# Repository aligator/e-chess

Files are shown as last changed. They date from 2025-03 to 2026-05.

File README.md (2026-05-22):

# E-Chess

# MOVED to https://codeberg.org/aligator/e-chess

This project is a physical chess board that is connected to an online chess
server (currently lichess).\
It allows to play chess on a physical board with a computer/remote opponent.

It is currently **WIP** so no full documentation and information is available
yet.\
However there exists already a working prototype including:

- ESP32-S3 Rust firmware
- Android app
- connection to lichess (to lichess via the android app using BLE - web on the
  esp32s3 was too unstable and slow)
- LEDs in the board to show the current game state
- 3d printable OpenSCAD file
- KiCAD electronics schematic

## Future plans

- more gameplay features
- ble over secure connection (currently unencrypted!)
- more easy hardware design (maybe PCB for the whole board?)
- Documentation
- ...

## AI Disclaimer

Yes, I use some AI for this project (especially for the Android app, since I am
not that interested in writing apps...), but the code-architecture, most
firmware code, scad, electronics and the overall design is my own.

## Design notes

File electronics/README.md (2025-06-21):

# E-Chess Electronics

This contains the schematic for the chess board.  
It is designed for an ESP32-S3 development board.  

Currently it is wired completely manually. Therefore it does not contain a PCB yet.

## LEDs

The schematic contains one single LED as placeholder for all 64 WS2812 LEDs.  
They are routed in a snake pattern from the top right to the bottom right.
```
┌💡─💡─💡─💡─💡─💡─💡─💡 <- START
└💡─💡─💡─💡─💡─💡─💡─💡┐
┌💡─💡─💡─💡─💡─💡─💡─💡┘
└💡─💡─💡─💡─💡─💡─💡─💡┐
┌💡─💡─💡─💡─💡─💡─💡─💡┘
└💡─💡─💡─💡─💡─💡─💡─💡┐
┌💡─💡─💡─💡─💡─💡─💡─💡┘
└💡─💡─💡─💡─💡─💡─💡─💡 -> END
``` 

## Reed sensors

For the Reed sensors a matrix with simple reed contacts is used.  
It resembles the matrix described [here](https://www-user.tu-chemnitz.de/~heha/Mikrocontroller/Tastenmatrix.htm).

The IO expander MCP23017 is used to connect the columns and rows.  
As it has exactly 16 pins, it matches exactly the required 8x8 matrix.

The MCP23017 has built in pull-up resistors, so no external resistors are needed.

GPB (pin 0 - 7) is used as output for the columns.  
GPA (pin 21 - 28) is used as input for the rows.  

The matrix resembles the actual chess board starting with A1 at the bottom left.  
So A1 == GPB0|GPA0, A2 == GPB1|GPA0, ... H8 == GPB7|GPA7.

To read the status, the firmware will set all rows but one to high and then read the columns.  
Then it will do the same for the next row.  

## Power supply

The ESP32-S3 is powered by the USB-C connector.  

* Since the esp works with 3.3V, the IO expander is also running on 3.3V.  
* Since the LEDs are WS2812B, they need 5V, coming from the ESP dev board. 
 **You may need to connect the IN-OUT jumper on the ESP dev board to receive 5V on the 5V-pin.**

For now my plan is to avoid driving the LEDS with full power.  
I try to handle everything with 500 mA. However this may need to be changed later.

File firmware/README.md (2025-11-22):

# E-Chess Firmware

This is the firmware for the E-Chess project, written in Rust using the ESP-IDF framework.

**This project works best with the ESP32-S3 (with 16mb flash) dev board.**
**The ESP32 is currently still in the firmware, but not recommended.**

For OTA to work, see the requirements in the [OTA Support](#ota-support) section.

## Prerequisites

- Rust (latest stable)
- ESP-IDF ([see the docs](https://docs.espressif.com/projects/rust/book/getting-started/toolchain.html))

## Quick Start

```bash
# Build, flash and watch logs (effectively cargo run)
./build.sh run esp32s3 --release

# Just watch logs via usb (if it is already running on the esp)
./build.sh watch

# Build and deploy via OTA (and optionally watch - only if connected via usb)
./build.sh ota 192.168.4.1 esp32s3 --release --watch
```

For more options and commands, run:
```bash
./build.sh --help
```

## OTA Support

For OTA updates, you need a flash size of at least 8MB *(16MB recommended!)* since the firmware is already > 2MB.
The flash must be partitioned with two slots.

**16MB is recommended!**  
8MB should also work for now, but the firmware may get bigger some day.  
Due to using rust std, this firmware is definitely not the smallest.

Either:
1. Copy the appropriate file (compatible to running with `cargo run`):
```bash
# For 8MB flash
cp espflash_ota_8mb.toml espflash.toml

# For 16MB flash
cp espflash_ota_16mb.toml espflash.toml
```

2. Or use the --partition-table flag:
```bash
# For 8MB flash
./build.sh run esp32s3 --flash-size 8mb

# For 16MB flash
./build.sh run esp32s3 --flash-size 16mb
```

## Development

1. Make sure you have all prerequisites installed
2. Connect your ESP32 via USB
3. Use `./build.sh run esp32s3 --watch` to build, flash and watch logs
4. Use `./build.sh watch` to just watch logs without building/flashing

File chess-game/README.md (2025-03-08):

# Rust Chess game

This project contains the base handling of a chess game.  
It can be run directly for testing by providing a cli prompt simulating the physical chess board.

As input it works with a single bit board that tells which square is occupied.
At any time this `physical` representation should only differ from the last observed state by one single part.
Otherwise it is not possible to distinguish what should happen in this step.

If the board gets in an invalid state it will stop doing anything.

If it is only one pice (either removed or added), it will be validated:
* based on the current game state (e.g. which player)
* if the last action is not complete yet, check if the new state completes it 
(e.g. moving a piece - 1. take it 2. place it on the new spot)
* is the move a valid chess move

To simulate the board for development there are only two comments to simulate the physical behavior:
* take b5
* put b5

after each action the cli prints out the new board state as ASCII.
The background color encodes the real chess color with black and grey for visualization.

But if a piece is wrong it is color coded this way:
* Blue - physical piece missing
* Red - physical piece should be here but it isn't

## Examples

### Simulator

The project includes a simulator example which can be run with:

```
cargo run --example simulator
```

This example requires the `reqwest` feature, which is enabled by default in the project configuration, so no additional flags are needed.

## Features

The project has the following features:

- `colored-debug`: Enables colored output in debug mode (enabled by default)
- `reqwest`: Enables a default implementation using reqwest and tokio

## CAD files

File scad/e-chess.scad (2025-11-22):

renderTopBoard = true;

// Enable multicolor using an extra layer.
renderLayeredMultiColorBoard = true;

// Switches the fields that get the extra layer. (e.g. to change the color on a specific layer manually.) Cannot be used together with renderMultiColorBoardColorX.
topBoardLayeredMultiColorEven = false;

// Enables multi-color Color1 (e.g. support for mulit-color printers.) Cannot be used together with topBoardLayeredMultiColorEven.
renderMultiColorBoardColor1 = false;
// Enables multi-color Color2 (e.g. support for mulit-color printers.) Cannot be used together with topBoardLayeredMultiColorEven.
renderMultiColorBoardColor2 = false;

renderTopGrid = true;
renderGrid = true;
renderBottom = true;
renderElectronicCase = true;
renderElectronicCaseCover = true;
renderReedPins = true;
// Just for debugging
renderMetalPlate = false;
flipElectronicCaseCover = false;
renderPCB = false;
pcbWidth = 179.4;
pcbHeight = 40.02;
pcbTopSpacing = 15;
pcbHoles = [
  [4.3, 4.3],
  [4.3, pcbHeight - 4.3],
  [148.7, pcbHeight / 2 + 0.45],
];
pcbSpacerHeight = 5;
pcbScrewDiameter = 4;
pcbSpacerDiameter = 8;

// Experimental - not really nice...
extraReedPinCutout = false;

// More easy to add the wires, but may lead to light bleeding into neightbour fields.
electronicCutoutInBorder = true;

renderPrintable = true;

cutParts = false;

// Also must match the led-strip led distance
fieldSize = 33;

// Board field count. For a normal chess -> 8.
size = 8;

top = 2.0;

topBoardHeight = 0.4;
topBoardMultiColorHeight = 0.2;

// Border on each field. Note that two borders side by side lead to an effective *2 border.
fieldBorder = 1;

wireRadius = 1.5;

boxHeight = 30;

ledWidth = 11;
ledHeight = 4;
bottomHeight = 5;

// Additional bottomWallSize to the size of the grid.
bottomWallSize = 5;

electronicCaseWidth = 50;
electronicBreakThrough = 9;

electronicCaseCover = 1;
electronicCaseCoverBorder = 1;
// Maybe use screws in the next version instead of the border?
// However my current printed prototype doesn't have this yet.
// electronicCaseCoverScrewsDiameter = 4;
// electronicCaseCoverScrewsOuterDiameter = 8;

// I use this display: Waveshare 1.54 Inch E-Paper Display Panel Module Kit 200 * 200 https://www.amazon.de/dp/B0728BJTZC?ref=ppx_yo2ov_dt_b_fed_asin_title
displayWidth = 32;
displayHeight = 38;
displayScrewDiameter = 3.3;
displayScrewOffsetX = -1.75;
displayScrewOffsetY = 2.8;
displaySpacerHeight = 1.5;
displayBottomSpacing = 3;
displayBottomOverlap = 6;

displaySpacerDiameter = displayScrewDiameter + (max(displayScrewOffsetX, displayScrewOffsetY) - displayScrewDiameter / 2) * 2;

// Offset of the buttons from the display edge (below the display).
displayButtonsOffsetY = 8;
// Spacing between the buttons.
displayButtonsSpacing = 15;
displayButtonDiameter = 7;

usbCutoutDia = 10;
usbCutoutDiaCover = 15;

reedPinBorder = 3;
metalPlateThickness = 0.3;
metalPlateRadius = 7.5;
reedThickness = 3.3;
reedWireThickness = 2;
reedOffset = 5;

tolerance = 0.4;

ledWallCutout = 2.0;

coverWidth = electronicCaseWidth - bottomWallSize - 2 * tolerance;

echo("available electronic width: ", coverWidth - 2 * electronicCaseCoverBorder);

reedPinHeight = boxHeight - topBoardHeight - top - metalPlateThickness;

// Just a constant to make cutouts larger for better preview rendering.
c0 = 0.01 + 0;

$fa = 3;
$fs = 0.2;

gridInner = size * fieldSize;
gridOuter = gridInner + 2 * fieldBorder;
cutPartsSize = cutParts ? 10 : 0;

fullOuterBoard = gridOuter + 2 * bottomWallSize + 2 * tolerance;

reedPinWidth = ledWidth + reedPinBorder * 2;

module eachGrid(count = size) {
  for (i = [0:1:count - 1]) {
    for (j = [0:1:count - 1]) {
      translate([i * fieldSize, j * fieldSize, 0]) children();
    }
  }
}

module cut4(partSize, gap) {
  if (gap == 0) {
    // Fast path to avoid unneeded rendering
    children();
  } else {
    for (i = [0:1:1]) {
      for (j = [0:1:1]) {
        translate(
          [i * partSize[0] / 2 + i * gap, j * partSize[1] / 2 + j * gap, 0]
        )
          intersection() {
            translate([-i * partSize[0] / 2, -j * partSize[1] / 2]) children();
            cube([partSize[0] / 2, partSize[1] / 2, partSize[2]]);
          }
      }
    }
  }
}

module cut2(partSize, gap, translation = [0, 0, 0]) {
  if (gap == 0) {
    // Fast path to avoid unneeded rendering
    children();
  } else {
    i = 0;
    for (j = [0:1:1]) {
      translate([0, j * partSize[1] / 2 + j * gap, 0]) intersection() {
          translate([0, -j * partSize[1] / 2]) children();
          translate(translation)
            cube([partSize[0], partSize[1] / 2, partSize[2]]);
        }
    }
  }
}

module Field(height) {
  difference() {
    cube([fieldSize, fieldSize, height]);
    translate([fieldBorder, fieldBorder, -c0]) cube(
        [
          fieldSize - fieldBorder * 2,
          fieldSize - fieldBorder * 2,
          height + c0 * 2,
        ]
      );
  }
  ;
}

module LayeredMultiColorBoard() {
  for (i = [0:1:size - 1]) {
    for (j = [0:1:size - 1]) {
      if ( (i + j) % 2 == (topBoardLayeredMultiColorEven ? 0 : 1)) {

        translate(
          [
            i * fieldSize,
            j * fieldSize,
            topBoardHeight,
          ]
        ) {
          cube(
            [
              fieldSize - tolerance * 2 - fieldBorder * 2,
              fieldSize - tolerance * 2 - fieldBorder * 2,
              topBoardMultiColorHeight,
            ]
          );
        }
        ;
      }
    }
  }
}

module MultiColorBoard1(count) {
  difference() {
    cube(
      [
        fieldSize * count,
        fieldSize * count,
        topBoardHeight,
      ]
    );

    for (i = [0:1:count - 1]) {
      for (j = [0:1:count - 1]) {
        if ( (i + j) % 2 == (renderPrintable ? 0 : 1)) {

          translate(
            [
              i * fieldSize,
              j * fieldSize,
              topBoardHeight - topBoardMultiColorHeight,
            ]
          ) {
            cube(
              [
                fieldSize,
                fieldSize,
                topBoardMultiColorHeight + c0,
              ]
            );
          }
          ;
        }
      }
    }
  }
}

module MultiColorBoard2(count) {
  for (i = [0:1:count - 1]) {
    for (j = [0:1:count - 1]) {
      if ( (i + j) % 2 == (renderPrintable ? 0 : 1)) {

        translate(
          [
            i * fieldSize,
            j * fieldSize,
            topBoardHeight - topBoardMultiColorHeight,
          ]
        ) {
          cube(
            [
              fieldSize,
              fieldSize,
              topBoardMultiColorHeight + c0,
            ]
          );
        }
        ;
      }
    }
  }
}

module BaseBoard() {
  cube(
    [
      gridInner - tolerance * 2 - fieldBorder * 2,
      gridInner - tolerance * 2 - fieldBorder * 2,
      topBoardHeight,
    ]
  );
}

module TopBoard() {
  // When rendering printable and with the multi color approach - render only one of the 4 parts.
  // Otherwise the handling in the slicer is hard.
  // You have to print it 4 times.
  multiColorSize = renderPrintable ? size / 2 : size;

  difference() {
    union() {
      if (!renderMultiColorBoardColor1 && !renderMultiColorBoardColor2) {
        translate([fieldBorder, fieldBorder, 0]) {
          BaseBoard();
          if (renderLayeredMultiColorBoard) {
            LayeredMultiColorBoard();
          }
        }
      }
      if (renderMultiColorBoardColor1) {
        MultiColorBoard1(multiColorSize);
      }
      ; if (renderMultiColorBoardColor2) {
        MultiColorBoard2(multiColorSize);
      }
      ;
    }
    ;

    // Cut away borders around the 4 slots.
    translate([0, (gridInner / 2) - tolerance * 2 - fieldBorder, -c0])
      cube([gridInner, fieldBorder * 2 + tolerance * 2, topBoardHeight + c0 * 2]);
    translate([(gridInner / 2) - tolerance * 2 - fieldBorder, 0, -c0])
      cube([fieldBorder * 2 + tolerance * 2, gridInner, topBoardHeight + c0 * 2]);

    translate([0, 0, -c0])
      difference() {
        cube(
          [
            gridInner,
            gridInner,
            topBoardHeight + topBoardMultiColorHeight + 2 * c0,
          ]
        );
        translate([fieldBorder, fieldBorder, 0]) {
          cube(
            [
              gridInner - tolerance * 2 - fieldBorder * 2,
              gridInner - tolerance * 2 - fieldBorder * 2,
              topBoardHeight + topBoardMultiColorHeight + 2 * c0,
            ]
          );
        }
        ;
      }
    ;
  }
}

module TopGrid() {
  difference() {
    union() {
      // Render border
      translate([0, 0, bottomHeight]) difference() {
          cube(
            [
              gridInner + fieldBorder * 2,
              gridInner + fieldBorder * 2,
              boxHeight,
            ]
          );
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

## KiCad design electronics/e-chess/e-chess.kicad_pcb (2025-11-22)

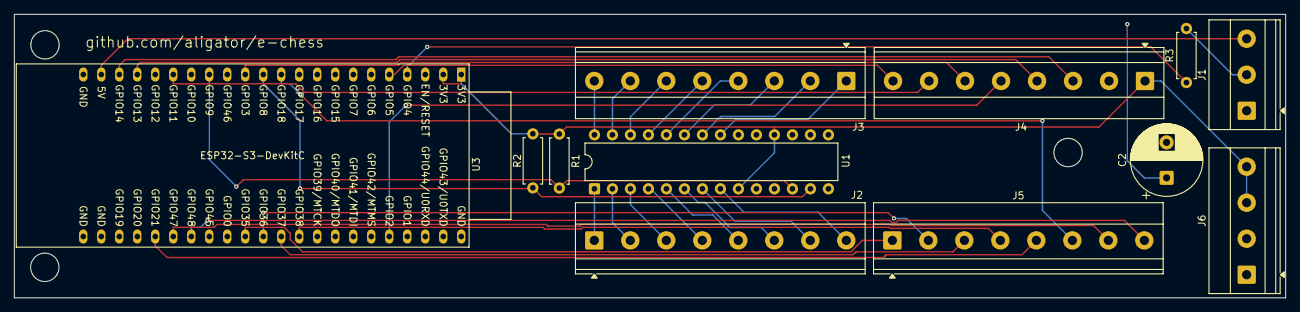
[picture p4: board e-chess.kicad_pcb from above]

Board: 2 copper layers, 179.4 x 40.0 mm, 15 parts (0 on the bottom side), 37 nets.

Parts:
C2: 470 µF; CP_Radial_D10.0mm_P5.00mm
J1: WS2812_LEDs; TerminalBlock_Phoenix_MKDS-1,5-3-5.08_1x03_P5.08mm_Horizont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
J2: Outputs; TerminalBlock_Phoenix_MKDS-1,5-8-5.08_1x08_P5.08mm_Horizont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
J3: Inputs; TerminalBlock_Phoenix_MKDS-1,5-8-5.08_1x08_P5.08mm_Horizont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
J4: e-Paper 1.54 inch; TerminalBlock_Phoenix_MKDS-1,5-8-5.08_1x08_P5.08mm_Horizont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
J5: Arbitary I/O; TerminalBlock_Phoenix_MKDS-1,5-8-5.08_1x08_P5.08mm_Horizont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
J6: Power for I/O; TerminalBlock_Phoenix_MKDS-1,5-4-5.08_1x04_P5.08mm_Horizont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
R1, R2: R4.7k; R_Axial_DIN0207_L6.3mm_D2.5mm_P7.62mm_Horizontal
R3: R470; R_Axial_DIN0207_L6.3mm_D2.5mm_P7.62mm_Horizontal
REF00, REF01, REF02: MountingHole_4mm
U1: MCP23017_SP; DIP-28_W7.62mm
U3: ESP32-S3-DevKitC

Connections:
+3.3V: J4.1 (VCC), J6.3 (3V3), J6.4 (3V3), R1.2, R2.2, U1.9 (VDD), U1.18 (~RESET), U3.1 (3V3), U3.2 (3V3)
+5V: C2.1, J1.3 (VDD), U3.21 (5V)
GND: C2.2, J1.1 (GND), J4.2 (GND), J6.1 (GND), J6.2 (GND), U1.10 (VSS), U1.15 (A0), U1.16 (A1), U1.17 (A2), U3.22 (GND), U3.23 (GND), U3.24 (GND), U3.44 (GND)
unnamed: J1.2 (DIN), R3.2
unnamed: J2.1, U1.1 (GPB0)
unnamed: J2.2, U1.2 (GPB1)
unnamed: J2.3, U1.3 (GPB2)
unnamed: J2.4, U1.4 (GPB3)
unnamed: J2.5, U1.5 (GPB4)
unnamed: J2.6, U1.6 (GPB5)
unnamed: J2.7, U1.7 (GPB6)
unnamed: J2.8, U1.8 (GPB7)
unnamed: J3.1, U1.21 (GPA0)
unnamed: J3.2, U1.22 (GPA1)
unnamed: J3.3, U1.23 (GPA2)
unnamed: J3.4, U1.24 (GPA3)
unnamed: J3.5, U1.25 (GPA4)
unnamed: J3.6, U1.26 (GPA5)
unnamed: J3.7, U1.27 (GPA6)
unnamed: J3.8, U1.28 (GPA7)
unnamed: J4.8 (BUSY), U3.5 (GPIO5/ADC1_CH4)
unnamed: J4.4 (CLK), U3.19 (GPIO13/ADC2_CH2)
unnamed: J4.5 (CS), U3.40 (GPIO2/ADC1_CH1)
unnamed: J4.6 (DC), U3.13 (GPIO3/ADC1_CH2)
unnamed: J4.3 (DIN), U3.20 (GPIO14/ADC2_CH3)
unnamed: J4.7 (RST), U3.17 (GPIO11/ADC2_CH0)
unnamed: J5.6 (GPIO18), U3.11 (GPIO18/ADC2_CH7)
unnamed: J5.5 (GPIO21), U3.27 (GPIO21)
unnamed: J5.1 (GPIO35), U3.32 (GPIO35)
unnamed: J5.2 (GPIO36), U3.33 (GPIO36)
unnamed: J5.3 (GPIO37), U3.34 (GPIO37)
unnamed: J5.4 (GPIO38), U3.35 (GPIO38)
unnamed: J5.7 (GPIO47), U3.28 (GPIO47)
unnamed: J5.8 (GPIO48), U3.29 (GPIO48)
unnamed: R1.1, U1.12 (SCK), U3.15 (GPIO9/ADC1_CH8)
unnamed: R2.1, U1.13 (SDA), U3.12 (GPIO8/ADC1_CH7)
unnamed: R3.1, U3.4 (GPIO4/ADC1_CH3)

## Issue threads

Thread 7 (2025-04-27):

without lichess api key it doesn't even allow to play offline

aligator, 2025-04-27:
Currently it does not load an offline game if no lichess key is configured.
It should be possible to play offline, when no key is configured.

Currently the game-page is not registered when no key is configured.
Maybe refactor wifi.rs & web.rs and combine them. no need to split the webpage.

Closed 2025-06-21.

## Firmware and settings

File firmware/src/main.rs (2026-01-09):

use crate::board::Board;
#[cfg(feature = "no_board")]
use crate::board::FakeBoard;
use crate::event::EventManager;
use crate::game::GameCommandEvent;
use anyhow::Result;
use board::MCP23017Board;
use chess::BitBoard;
use chess_game::game::ChessGameState;
use eink_display::ChessEinkDisplay;
use embedded_hal::spi::SpiDevice;
use esp_idf_hal::gpio::{Gpio0, PinDriver};
use esp_idf_hal::peripherals::Peripherals;
use esp_idf_hal::prelude::*;
use esp_idf_hal::rmt::TxRmtDriver;
use esp_idf_hal::spi::config::DriverConfig;
use esp_idf_hal::spi::{SpiConfig, SpiDeviceDriver, SpiDriver};
use esp_idf_hal::{i2c::*, rmt::config::TransmitConfig};
use game::GameStateEvent;
use log::*;
use std::thread::sleep;
use std::time::Duration;
use ws2812_esp32_rmt_driver::Ws2812Esp32Rmt;

mod bluetooth;
mod board;
mod constants;
mod display;
mod eink_display;
mod event;
mod game;
mod util;

#[derive(Debug, Clone)]
enum Event {
    GameState(GameStateEvent),
    GameCommand(GameCommandEvent),
}

unsafe impl Send for Event {}
unsafe impl Sync for Event {}

fn run_game<'a, ButtonA, ButtonB, SPI, BUSY, DC, RST, DELAY>(
    mcp23017: I2cDriver<'_>,
    ws2812: Ws2812Esp32Rmt,
    eink_display: &mut ChessEinkDisplay<ButtonA, ButtonB, SPI, BUSY, DC, RST, DELAY>,
    event_manager: &EventManager<Event>,
) -> Result<()>
where
    ButtonA: embedded_hal::digital::InputPin,
    ButtonB: embedded_hal::digital::InputPin,
    SPI: SpiDevice,
    BUSY: embedded_hal::digital::InputPin,
    DC: embedded_hal::digital::OutputPin,
    RST: embedded_hal::digital::OutputPin,
    DELAY: embedded_hal::delay::DelayNs + 'a,
{
    #[cfg(not(feature = "no_board"))]
    let mut board: Box<dyn Board> = Box::from(MCP23017Board::new(mcp23017, 0x20));
    #[cfg(feature = "no_board")]
    let mut board: Box<dyn Board> = Box::from(FakeBoard {});

    board.setup()?;

    let mut display = display::Display::new(ws2812);
    display.setup()?;

    game::run_game(event_manager);

    // Start the main loop
    info!("Start app loop");

    let rx = event_manager.create_receiver();
    let tx = event_manager.create_sender();
    let mut last_physical = BitBoard::new(0);
    let mut last_game_state: Option<ChessGameState> = None;

    // Always start with a local game (standard chess position)
    let initial_game_id = "rnbqkbnr/pppppppp/8/8/8/8/PPPPPPPP/RNBQKBNR w KQkq - 0 1".to_string();

    tx.send(Event::GameCommand(GameCommandEvent::LoadNewGame {
        game_key: initial_game_id,
    }))?;

    // Start the event manager after setting up everything.
    event_manager.start_thread();
    loop {
        // Tick the physical board
        let physical = board.tick(last_physical)?;
        if physical != last_physical {
            last_physical = physical;
            if let Err(e) = tx.send(Event::GameCommand(GameCommandEvent::UpdatePhysical {
                bitboard: physical,
            })) {
                warn!("Failed to send update physical event: {:?}", e);
            }
        }

        // Check if event happens
        if let Ok(event) = rx.try_recv() {
            match event.clone() {
                Event::GameState(game_state_event) => match game_state_event {
                    GameStateEvent::UpdateGame(game_state) => {
                        info!("Received update game state event: {:?}", game_state);

                        last_game_state = Some(game_state);
                    }
                    _ => {}
                },
                _ => {}
            }
        }

        display.tick(&last_game_state)?;
        eink_display.tick(physical, &last_game_state)?;
    }
}

/// Entry point to our application.
fn main() -> Result<()> {
    // It is necessary to call this function once. Otherwise some patches to the runtime
    // implemented by esp-idf-sys might not link properly. See https://github.com/esp-rs/esp-idf-template/issues/71
    esp_idf_svc::sys::link_patches();

    // Bind the log crate to the ESP Logging facilities
    esp_idf_svc::log::EspLogger::initialize_default();

    let peripherals = Peripherals::take().unwrap();

    info!("Starting E-Chess!");
    #[cfg(esp32)]
    info!("Running on ESP32");
    #[cfg(esp32s3)]
    info!("Running on ESP32S3");

    // Initialize the I2C bus for the MCP23017
    let config = I2cConfig::new().baudrate(100.kHz().into());
    #[cfg(esp32)]
    let mcp23017: I2cDriver<'_> = {
        let sda = peripherals.pins.gpio21;
        let scl = peripherals.pins.gpio22;
        I2cDriver::new(peripherals.i2c0, sda, scl, &config)?
    };
    #[cfg(esp32s3)]
    let mcp23017: I2cDriver<'_> = {
        let sda = peripherals.pins.gpio8;
        let scl = peripherals.pins.gpio9;
        I2cDriver::new(peripherals.i2c0, sda, scl, &config)?
    };

    let driver_config = TransmitConfig::new()
        .clock_divider(1) // Required parameter.
        .mem_block_num(8); // Increase the number depending on your code.

    // Initialize the RMT driver for the WS2812
    #[cfg(esp32)]
    let driver = TxRmtDriver::new(
        peripherals.rmt.channel0,
        peripherals.pins.gpio23,
        &driver_config,
    )?;
    #[cfg(esp32s3)]
    let driver = TxRmtDriver::new(
        peripherals.rmt.channel0,
        peripherals.pins.gpio4,
        &driver_config,
    )?;
    let ws2812 = Ws2812Esp32Rmt::new_with_rmt_driver(driver)?;

    // Initialize the SPI bus for the E-Paper display
    let spi_config = SpiConfig::new()
        .baudrate(Hertz(4_000_000))
        .data_mode(esp_idf_hal::spi::config::MODE_0);
    let driver_config = DriverConfig::new();
    // Create delay provider
    let delay = esp_idf_hal::delay::Ets;
    #[cfg(esp32)]
    let (spi_driver, cs, busy, dc, rst, button_a, button_b) = {
        let spi = peripherals.spi2;
        let sclk = peripherals.pins.gpio18;
        let mosi = peripherals.pins.gpio23;
        let cs = peripherals.pins.gpio5;
        let dc = peripherals.pins.gpio2;
        let busy = peripherals.pins.gpio4;
        let rst = peripherals.pins.gpio0;

        let spi_driver = SpiDriver::new(spi, sclk, mosi, Option::<Gpio0>::None, &driver_config)?;

        let button_a = peripherals.pins.gpio35;
        let button_b = peripherals.pins.gpio36;

        (spi_driver, cs, busy, dc, rst, button_a, button_b)
    };

    #[cfg(esp32s3)]
    let (spi_driver, cs, busy, dc, rst, button_a, button_b) = {
        let spi = peripherals.spi2;
        let sclk = peripherals.pins.gpio13;
        let mosi = peripherals.pins.gpio14;
        let cs = peripherals.pins.gpio2;
        let dc = peripherals.pins.gpio3;
        let busy = peripherals.pins.gpio5;
        let rst = peripherals.pins.gpio11;

        let spi_driver = SpiDriver::new(spi, sclk, mosi, Option::<Gpio0>::None, &driver_config)?;

        let button_a = peripherals.pins.gpio35;
        let button_b = peripherals.pins.gpio36;

        (spi_driver, cs, busy, dc, rst, button_a, button_b)
    };
    let spi = SpiDeviceDriver::new(spi_driver, Some(cs), &spi_config)?;

    // Setup the button pins and enable the internal pullup.
    let mut button_a_driver = PinDriver::input(button_a)?;
    button_a_driver.set_pull(esp_idf_hal::gpio::Pull::Up)?;
    let mut button_b_driver = PinDriver::input(button_b)?;
    button_b_driver.set_pull(esp_idf_hal::gpio::Pull::Up)?;

    let event_manager = EventManager::<Event>::new();

    let mut eink_display = eink_display::ChessEinkDisplay::new(
        button_a_driver,
        button_b_driver,
        spi,
        PinDriver::input(busy)?,
        PinDriver::output(dc)?,
        PinDriver::output(rst)?,
        delay,
        None,
        &event_manager,
    )?;

    eink_display.setup()?;

    match run_game(mcp23017, ws2812, &mut eink_display, &event_manager) {
        Ok(_) => {
            warn!("Stopping game loop");
            Ok(())
        }
        Err(e) => {
            warn!("Stopping game loop due to error: {:?}", e);
            loop {
                sleep(Duration::from_millis(1000));
            }
        }
    }
}

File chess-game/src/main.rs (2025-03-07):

use game::ChessGame;
use lichess::LichessConnector;
use request::Request;
use std::future::Future;
use std::io::{self, Write};

mod bitboard_extensions;
mod chess_connector;
mod game;
mod lichess;
mod request;
mod requester;

#[tokio::main]
async fn main() {
    println!("Chess board simulator");

    let api_key = std::env::var("LICHESS_API_KEY").unwrap_or_else(|_| {
        let args: Vec<String> = std::env::args().collect();
        if args.len() < 2 {
            eprintln!(
                "Please provide API key as argument or set LICHESS_API_KEY environment variable"
            );
            std::process::exit(1);
        }
        args[1].clone()
    });

    let id = std::env::var("GAME_ID").unwrap_or_else(|_| {
        let args: Vec<String> = std::env::args().collect();
        if args.len() < 3 {
            String::new()
        } else {
            args[2].clone()
        }
    });

    let mut game =
        ChessGame::new(LichessConnector::new(Request { api_key: api_key }), &id).unwrap();

    let mut physical_board = game.expected_physical();
    // Start with all set correctly.
    game.physical = physical_board;

    println!("{:?}", game);

    loop {
        print!("> ");
        io::stdout().flush().unwrap();

        let mut input = String::new();
        io::stdin().read_line(&mut input).unwrap();
        let input = input.trim().to_lowercase();

        // Parse commands
        if input.starts_with("take ")
            || input.starts_with("put ")
            || input.starts_with("t ")
            || input.starts_with("p ")
        {
            let parts: Vec<&str> = input.split_whitespace().collect();
            if parts.len() != 2 {
                println!("Invalid command format. Use 'take b5' or 'put b5'");
                continue;
            }

            let square = parts[1];
            // Convert algebraic notation (e.g. "b5") to board position
            if let Some(pos) = parse_square(square) {
                let mask = 1u64 << pos;

                match parts[0] {
                    "take" => physical_board.0 &= !mask, // Clear the bit
                    "t" => physical_board.0 &= !mask,    // Clear the bit
                    "put" => physical_board.0 |= mask,   // Set the bit
                    "p" => physical_board.0 |= mask,     // Set the bit
                    _ => unreachable!(),
                }

                game.tick(physical_board);

                // Print the game state
                println!("{:?}", game);
            } else {
                println!("Invalid square notation. Use a1-h8");
            }
        } else if input == "quit" || input == "exit" {
            break;
        } else {
            println!(
                "Unknown command. Valid commands are: 'take <square>', 'put <square>', 'quit'"
            );
        }
    }
}

/// Converts algebraic notation (e.g. "b5") to a board position (0-63)
fn parse_square(square: &str) -> Option<u32> {
    if square.len() != 2 {
        return None;
    }

    let file = square.chars().next().unwrap();
    let rank = square.chars().nth(1).unwrap();

    if !('a'..='h').contains(&file) || !('1'..='8').contains(&rank) {
        return None;
    }

    let file_idx = (file as u8 - b'a') as u32;
    let rank_idx = (rank as u8 - b'1') as u32;

    Some(rank_idx * 8 + file_idx)
}

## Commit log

2024-06-23 Add scad model
    [e-chess.scad]
2024-06-23 Beginn redesign of the 3d model
    [e-chess.scad]
2024-06-26 Add grid
    [e-chess.scad]
2024-06-30 Fix grid rendering
    [e-chess.scad]
2024-06-30 Add printing tolerance
    [e-chess.scad]
2024-06-30 Add bottom plate
    [e-chess.scad]
2024-06-30 Add cutting into 4 parts for smaller printers
    [e-chess.scad]
2024-07-07 Better default values
    [e-chess.scad]
2024-07-14 Implement simple firmware for prototype 2 including neopixels
2024-07-14 Use esp32 board
2024-07-14 Restructure project and add a rust firmware
    [e-chess.scad]
2024-07-14 experiment with leds
2024-07-21 Cleanup and use pin 23 for led
2024-07-27 Move wifi setup into extra thread on core0
2024-07-27 Implement first bits for a TicTacToe board
2024-07-28 Implement board history
2024-08-02 Hide led wiring
    [e-chess.scad]
2024-08-02 Only expose one strip through the wall
    [e-chess.scad]
2024-08-02 Enable all by default
    [e-chess.scad]
2024-08-04 Add electronics box with a cover hold by magnets
    [e-chess.scad]
2024-08-04 Fix cutting
    [e-chess.scad]
2024-08-04 Add stamps to the cover at the center
    [e-chess.scad]
2024-08-24 Improve 3d model cutout and tollerance
    [e-chess.scad]
2024-08-24 Add option to render all as printable at once
    [e-chess.scad]
2024-08-24 Fix led size
    [e-chess.scad]
2024-08-24 Fix wire hole
    [e-chess.scad]
2024-08-25 Improve electronic cover
    [e-chess.scad]
2024-12-15 Split top into board and grid
    [e-chess.scad]
2024-12-15 More stable defaults for the top grid
    [e-chess.scad]
2024-12-15 Cleanup and auto refomrat with a better code style
    [e-chess.scad]
2024-12-18 Fix top
    [e-chess.scad]
2024-12-19 Higher top
    [e-chess.scad]
2024-12-25 Fix top grid height
    [e-chess.scad]
2024-12-31 bigger bottomWallSize
    [e-chess.scad]
2025-01-06 Fix wire routing and even bigger bottom wall size
    [e-chess.scad]
2025-01-12 Add Reed Pins
    [e-chess.scad]
2025-01-12 Fix grid and topGrid
    [e-chess.scad]
2025-01-12 Fix top board sizing
    [e-chess.scad]
2025-01-12 Fix bottom case size
    [e-chess.scad]
2025-01-12 Fix reed pins
    [e-chess.scad]
2025-01-12 Improve reed pins
    [e-chess.scad]
2025-01-12 Move wires from the grid to the bottom.
    [e-chess.scad]
2025-01-12 make default printable
    [e-chess.scad]
2025-01-12 Set correct reed defaults
    [e-chess.scad]
2025-01-13 Improve wire holes
    [e-chess.scad]
2025-01-14 Improve electronic layout
    [e-chess.scad]
2025-01-15 Add hole for usb cable
    [e-chess.scad]
2025-01-15 Reduce bridging size in the led strip-cutouts in the walls
    [e-chess.scad]
2025-01-15 Add option for the top board to be multicolor by adding an extra layer.
    It can be confugured to alternate even or odd, and the additional height can be set (e.g. 0.2mm)
    [e-chess.scad]
2025-01-15 fix LedStripWiresInWalls for odd board sizes
    [e-chess.scad]
2025-01-15 Increase reed offset for better detection
    [e-chess.scad]
2025-01-15 Simulate taking and placing physical pieces completely and display wrong ones.
    [main.rs]
2025-01-16 Reed pins printable without support
    [e-chess.scad]
2025-01-16 Implement board for chess
2025-01-16 Remove wrong double cut4 on the reed pins
    [e-chess.scad]
2025-02-16 Implement board with the i2c i/o expander
2025-02-17 Implement Display with the leds
2025-02-18 Fix led mapping
2025-02-22 Fix board to shift the bits to correct position
    [board.rs]
2025-03-05 Begin implementing connector for online mode
2025-03-07 Start implementing the Lichess Connector
2025-03-09 Fix error handling for the lib and start implementing the requester for the esp
    [main.rs]
2025-03-09 Make stream async as it should be and avoid auto-restart on api error to avoid spamming requests
    [main.rs]
2025-03-09 First working POC connecting the physical board to lichess
2025-03-15 avoid stopping game loop on error
    [main.rs]
2025-03-15 Fix board streaming
2025-03-15 Improve colorizing to also colorize the currently in-move-piece, improve loading indicator
2025-03-19 Fix ignoring broken board state.
    Now it should stop any processing of the physical state if more than one piece is "being moved"
    [main.rs]
2025-03-19 Update ws2812-esp32-rmt-driver to incorporate the new mem block fix to mitigate flickering
    [main.rs]
2025-03-24 Simplify types of the game and connector. Now it is possible to exchange the implementation.
2025-04-17 Support if the remote board takes back a step - effectively resets the game for now.
2025-04-26 Add inner walls on the bottom part to better glue them together if split
    [e-chess.scad]
2025-04-26 Adapt the grid to split it into 4 slots
    [e-chess.scad]
2025-04-26 Fix grid and top grid to match properly
    [e-chess.scad]
2025-04-26 Adapt the topBoard
    [e-chess.scad]
2025-04-26 Rotate the reed so that is diagonal. This is better because now it is in the shadow of the pin itself - and therefore doesn't cast a new shadow
    [e-chess.scad]
2025-04-26 Cut wires into the borders between the slots
    [e-chess.scad]
2025-04-27 Make initial setup more robust, fix css not served initially
    [main.rs]
2025-04-27 Add support for esp32 S3
    [partitions_16.csv]
2025-04-27 Select pins based on the board type
2025-04-27 Fix wifi config loading and avoid cfg warning
    [main.rs]
2025-04-27 Fix initial game loading of a new, local game
    [main.rs]
2025-05-03 Improve electronic break trhough and usb
    [e-chess.scad]
2025-05-07 Add OTA functionality
    [partitions_8.csv]
2025-05-29 Put game into own thread
2025-06-08 Fix top part
    [e-chess.scad]
2025-06-15 Support Printing the top with a multicolor printer
    [e-chess.scad]
2025-06-19 simplify multicolor a bit
    [e-chess.scad]
2025-06-19 Sleep thread a bit to avoid blocking the core
    [main.rs]
2025-06-21 Fix game state sending
    [main.rs]
2025-06-21 Add new game button to start a new local game
2025-06-21 Add kicad schematics and some documentation
    [e-chess.kicad_pcb, e-chess.kicad_sch]
2025-06-21 Fix led order docu
    [e-chess.kicad_sch]
2025-06-22 Add link to https://www.instructables.com/Low-Cost-Automation-ESP32-and-16-Relays/
    [e-chess.kicad_sch]
2025-06-22 Improve electronic cutouts to match the new reed location & orientation
    [e-chess.scad]
2025-10-25 Improve electroinic schmeatics
    [e-chess.kicad_pcb, e-chess.kicad_sch]
2025-10-25 Draw PCB
    [e-chess.kicad_pcb, e-chess.kicad_sch]
2025-10-25 change exposed pins a bit
    [e-chess.kicad_pcb, e-chess.kicad_sch]
2025-10-28 Add info page navigation using a button
2025-11-11 Add display cutot to the electronic cover
    [e-chess.scad]
2025-11-11 Add holes for buttons
    [e-chess.scad]
2025-11-11 Add border for the electronic cover
    [e-chess.scad]
2025-11-19 set button hole size to 7
    [e-chess.scad]
2025-11-22 make display screws a bit bigger
    [e-chess.scad]
2025-11-22 Place display at the bottom
    [e-chess.scad]
2025-11-22 Move terminals a bit in to have more space for the cables
    [e-chess.kicad_pcb]
2025-11-22 Add pcb 3d model to scad for visualization
    [e-chess.scad]
2025-11-22 Add screw holes for the pcb
    [e-chess.scad]
2025-11-22 Improve display positioning
    [e-chess.scad]
2025-11-22 Add display overlap for a nicer look
    [e-chess.scad]
2025-11-22 Fix pcb screw
    [e-chess.scad]
